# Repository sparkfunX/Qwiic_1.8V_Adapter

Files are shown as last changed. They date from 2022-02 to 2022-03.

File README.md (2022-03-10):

SparkFun Qwiic 1.8V Adapter
========================================

Qwiic 1.8V Adapter

[*Qwiic 1.8V Adapter (SPX-19017)*](https://www.sparkfun.com/products/19017)

Our [Qwiic Connect System](https://www.sparkfun.com/qwiic) is designed to help you quickly interface development boards and breakouts in your project or prototype. One way the Qwiic system achieves this is by standardizing on a single bus voltage of 3.3 Volts. This means that any Qwiic-compatible board that's based on a 1.8V part has an on-board voltage regulator and logic level translator, but what if you have a 1.8V part with no breakout board and you need to get integrated into your Qwiic project? No worries! This Qwiic 1.8V Adapter supplies 1.8V at up to 300mA as well as bi-directional logic level translation so that you can connect your Qwiic system to any 1.8V I²C part you can find! Simply connect the adapter to your bus using a Qwiic cable, connect your 1.8V part to the header pins marked "1.8V," and now your part is on the 3.3V Qwiic bus! As on other Qwiic boards, we've also broken out the 3.3V pins to a 0.1" header and added two Qwiic connectors, making it easy to connect in line with all of your other Qwiic boards.

Repository Contents
-------------------

* **/Documentation** - Data sheets, additional product information
* **/Hardware** - Eagle design files (.brd, .sch)
* **/Production** - Production panel files (.brd)

License Information
-------------------

This product is _**open source**_! 

Please review the LICENSE.md file for license information. 

If you have any questions or concerns on licensing, please contact technical support on our [SparkFun forums](https://forum.sparkfun.com/viewforum.php?f=152).

Distributed as-is; no warranty is given.

- Your friends at SparkFun.

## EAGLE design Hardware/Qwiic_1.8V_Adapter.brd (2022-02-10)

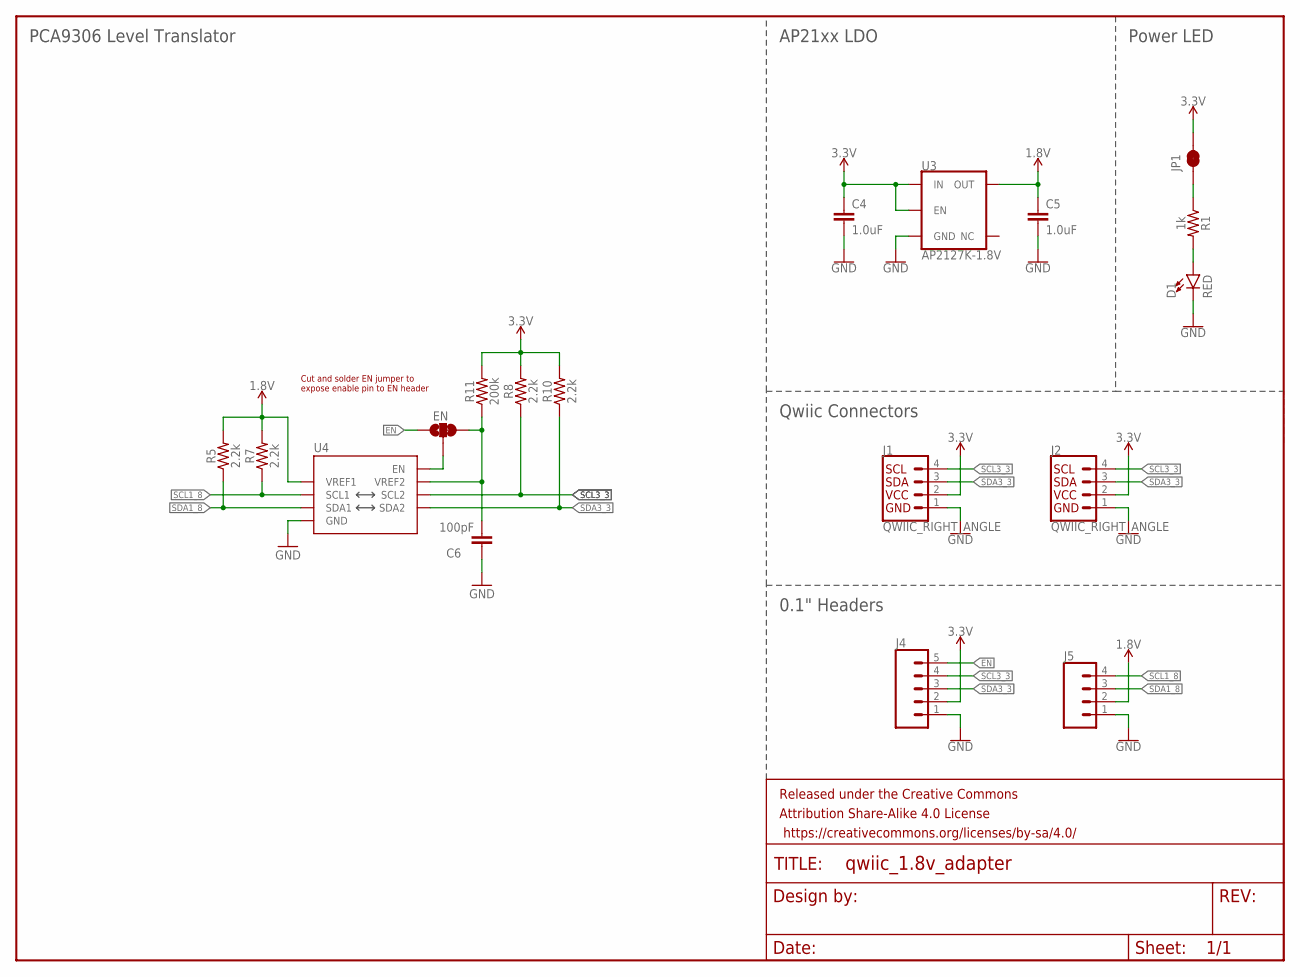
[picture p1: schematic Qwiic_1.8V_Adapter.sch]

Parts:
C4, C5: 1.0uF; 0603
C6: 100pF; 0603
D1: RED; LED-0603
EN: JUMPER-SMT_3_1-NC_TRACE_SILK; SMT-JUMPER_3_1-NC_TRACE_SILK
FRAME1: FRAME-LETTER; CREATIVE_COMMONS
J1, J2: QWIIC_RIGHT_ANGLE; JST04_1MM_RA
J4: CONN_05NO_SILK; 1X05_NO_SILK
J5: CONN_041X04_NO_SILK; 1X04_NO_SILK
JP1: JUMPER-SMT_2_NC_TRACE_SILK; SMT-JUMPER_2_NC_TRACE_SILK
R1: 1k; 0603
R5, R7, R8, R10: 2.2k; 0603
R11: 200k; 0603
U3: AP2127K-1.8V; SOT23-5
U4: PCA9306VSSOP_8PIN; VSSOP_8PIN

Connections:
1.8V: C5.1, J5.2, R5.2, R7.2, U3.5 (OUT), U4.P2 (VREF1)
3.3V: C4.1, J1.2, J2.2, J4.2, JP1.2, R8.2, R10.2, R11.2, U3.1 (IN), U3.3 (EN)
EN: EN.1, J4.5
GND: C4.2, C5.2, C6.1, D1.C, J1.1, J2.1, J4.1, J5.1, U3.2 (GND), U4.P1 (GND)
unnamed: EN.2, U4.P8 (EN)
unnamed: D1.A, R1.2
unnamed: JP1.1, R1.1
unnamed: C6.2, EN.3, R11.1, U4.P7 (VREF2)
SCL1_8: J5.4, R7.1, U4.P3 (SCL1)
SCL3_3: J1.4, J2.4, J4.4, R8.1, U4.P6 (SCL2)
SDA1_8: J5.3, R5.1, U4.P4 (SDA1)
SDA3_3: J1.3, J2.3, J4.3, R10.1, U4.P5 (SDA2)

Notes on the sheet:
PCA9306 Level Translator
AP21xx LDO
Power LED
Qwiic Connectors
0.1" Headers
Cut and solder EN jumper to expose enable pin to EN header

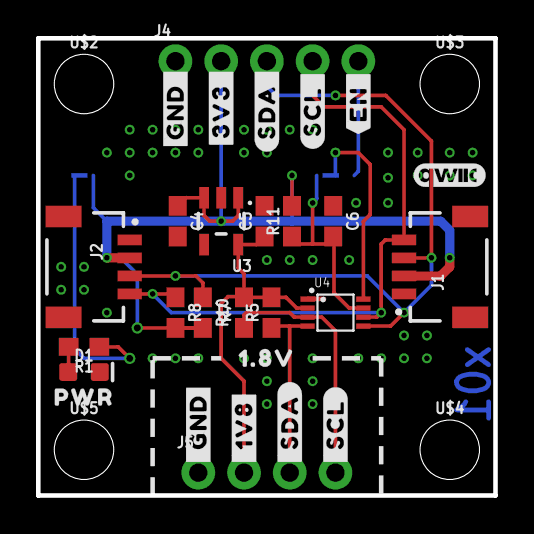
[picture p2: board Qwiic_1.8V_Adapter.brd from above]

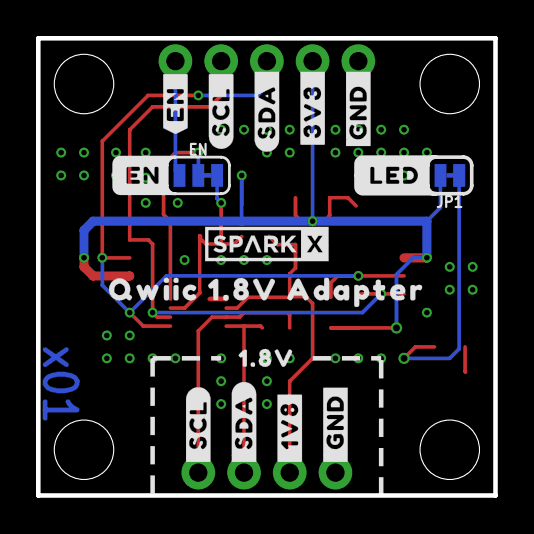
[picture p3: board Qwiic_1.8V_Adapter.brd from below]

Board: 2 copper layers, 25.4 x 25.4 mm, 49 parts (16 on the bottom side), 12 nets.

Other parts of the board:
U$1, U$17: #_GND#0
U$2, U$3, U$4, U$5: STAND-OFF
U$6, U$18: #_1V8#0
U$7, U$19: #_SDA#0
U$8, U$20: #_SCL#0
U$9: PWR0
U$10, U$21: #GND_#0
U$11, U$22: #3V3_#0
U$12, U$23: #SDA_#0
U$13, U$24: #SCL_#0
U$14, U$25: #EN_#0
U$15, U$26: 1#8V0
U$16: QWIIC_4MM
U$27: #EN#0
U$28: QWIIC_1#8V_ADAPTER0
U$29: SPARKX-SMALL
U$30: #LED#0

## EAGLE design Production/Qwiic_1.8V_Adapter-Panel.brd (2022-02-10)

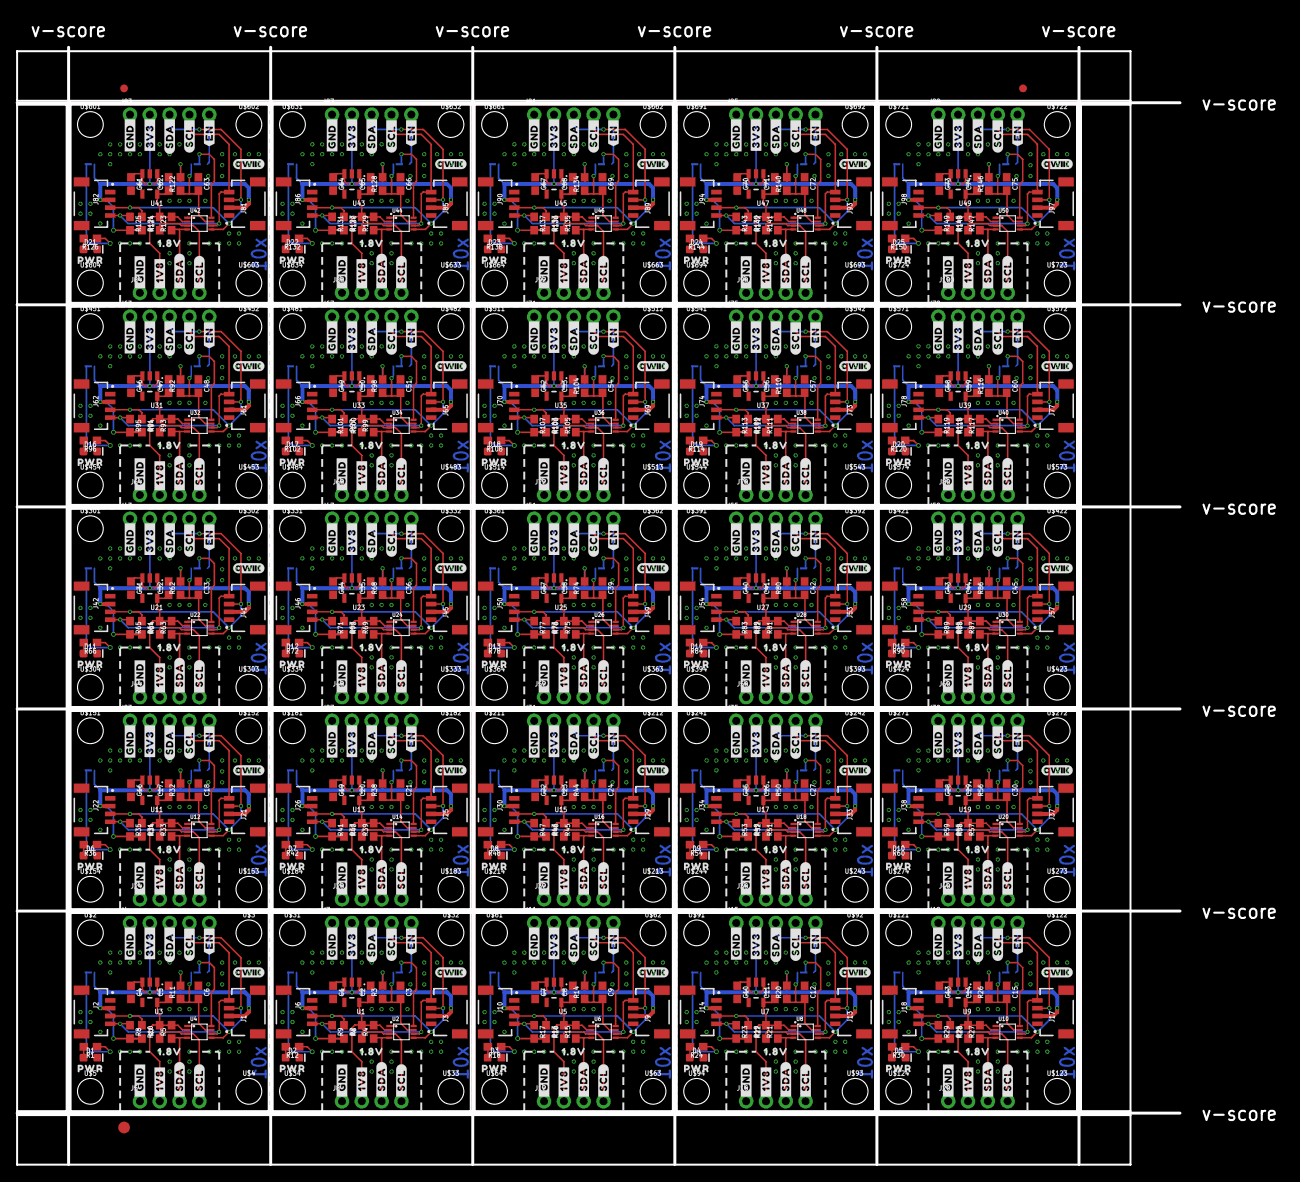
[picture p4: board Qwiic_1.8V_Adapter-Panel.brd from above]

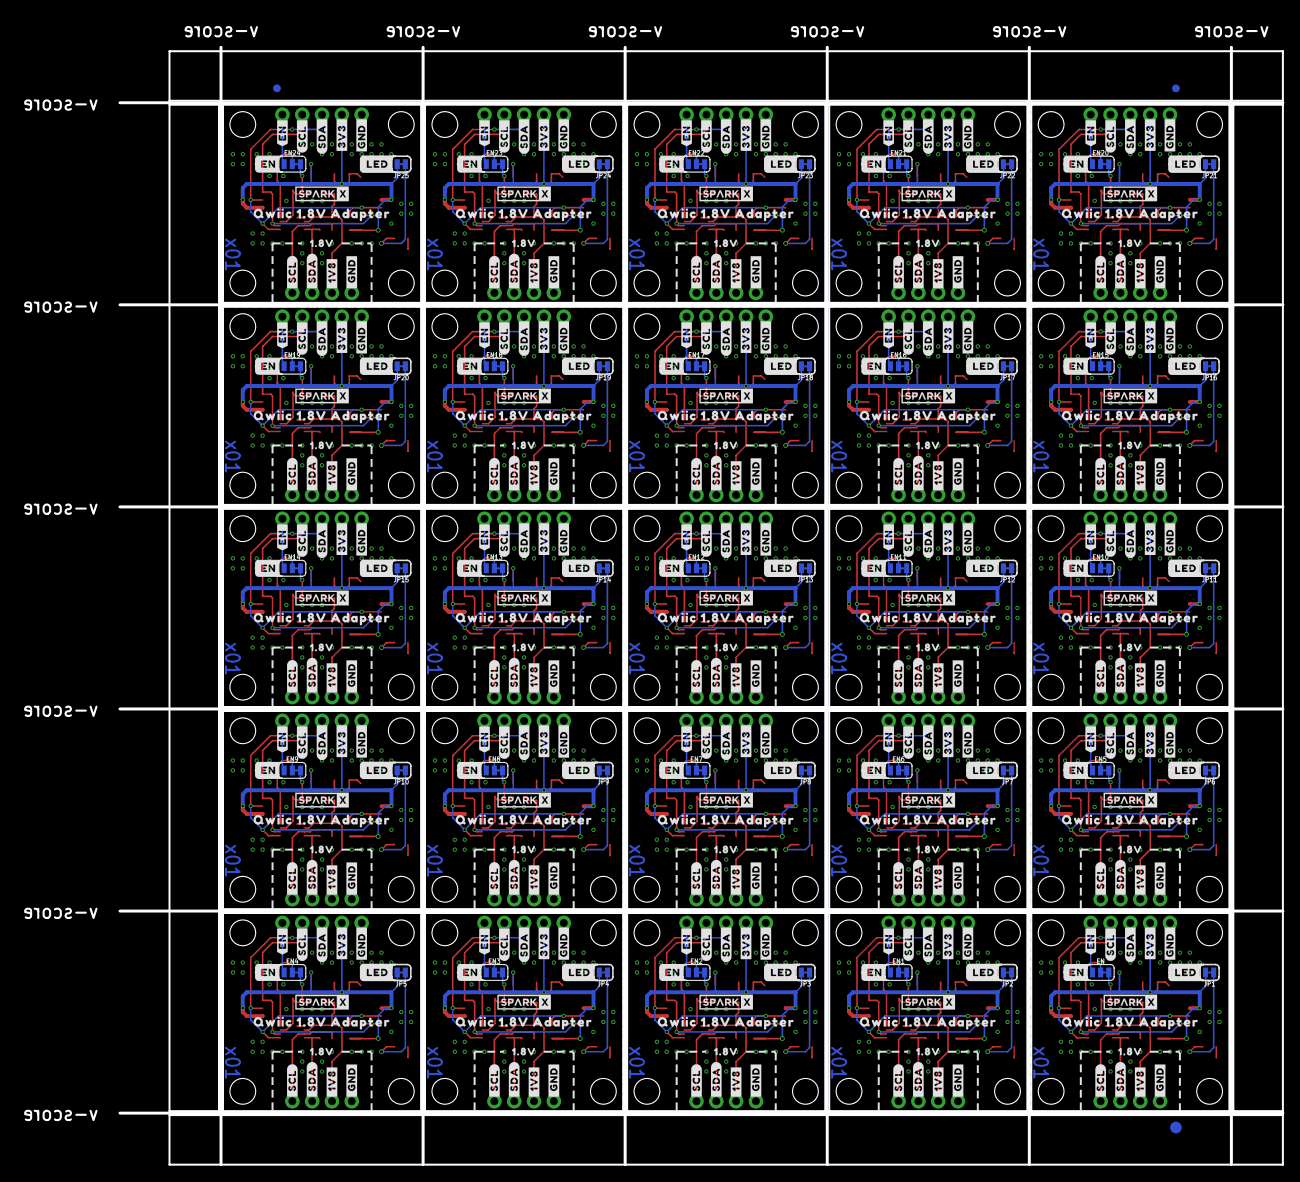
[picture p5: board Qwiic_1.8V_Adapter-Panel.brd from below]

Board: 2 copper layers, 149.1 x 143.3 mm, 1206 parts (403 on the bottom side), 300 nets.

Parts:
C1, C2, C4, C5, C7, C8, C10, C11, C13, C14, C16, C17, C19, C20, C22, C23, C25, C26, C28, C29, C31, C32, C34, C35, C37, C38, C40, C41, C43, C44, C46, C47, C49, C50, C52, C53, C55, C56, C58, C59, C61, C62, C64, C65, C67, C68, C70, C71, C73, C74: 1.0uF; 0603
C3, C6, C9, C12, C15, C18, C21, C24, C27, C30, C33, C36, C39, C42, C45, C48, C51, C54, C57, C60, C63, C66, C69, C72, C75: 100pF; 0603
D1, D2, D3, D4, D5, D6, D7, D8, D9, D10, D11, D12, D13, D14, D15, D16, D17, D18, D19, D20, D21, D22, D23, D24, D25: RED; LED-0603
E$1, E$2, E$3, E$4: FIDUCIAL-1X2
E$5, E$6: FIDUCIAL-1.5X3
EN, EN1, EN2, EN3, EN4, EN5, EN6, EN7, EN8, EN9, EN10, EN11, EN12, EN13, EN14, EN15, EN16, EN17, EN18, EN19, EN20, EN21, EN22, EN23, EN24: JUMPER-SMT_3_1-NC_TRACE_SILK; SMT-JUMPER_3_1-NC_TRACE_SILK
J1, J2, J3, J6, J9, J10, J13, J14, J17, J18, J21, J22, J25, J26, J29, J30, J33, J34, J37, J38, J41, J42, J45, J46, J49, J50, J53, J54, J57, J58, J61, J62, J65, J66, J69, J70, J73, J74, J77, J78, J81, J82, J85, J86, J89, J90, J93, J94, J97, J98: QWIIC_RIGHT_ANGLE; JST04_1MM_RA
J4, J7, J11, J15, J19, J23, J27, J31, J35, J39, J43, J47, J51, J55, J59, J63, J67, J71, J75, J79, J83, J87, J91, J95, J99: 1X05_NO_SILK
J5, J8, J12, J16, J20, J24, J28, J32, J36, J40, J44, J48, J52, J56, J60, J64, J68, J72, J76, J80, J84, J88, J92, J96, J100: 1X04_NO_SILK
JP1, JP2, JP3, JP4, JP5, JP6, JP7, JP8, JP9, JP10, JP11, JP12, JP13, JP14, JP15, JP16, JP17, JP18, JP19, JP20, JP21, JP22, JP23, JP24, JP25: JUMPER-SMT_2_NC_TRACE_SILK; SMT-JUMPER_2_NC_TRACE_SILK
R1, R12, R18, R24, R30, R36, R42, R48, R54, R60, R66, R72, R78, R84, R90, R96, R102, R108, R114, R120, R126, R132, R138, R144, R150: 1k; 0603
R2, R4, R5, R6, R7, R8, R9, R10, R13, R15, R16, R17, R19, R21, R22, R23, R25, R27, R28, R29, R31, R33, R34, R35, R37, R39, R40, R41, R43, R45, R46, R47, R49, R51, R52, R53, R55, R57, R58, R59, R61, R63, R64, R65, R67, R69, R70, R71, R73, R75, R76, R77, R79, R81, R82, R83, R85, R87, R88, R89, R91, R93, R94, R95, R97, R99, R100, R101, R103, R105, R106, R107, R109, R111, R112, R113, R115, R117, R118, R119, R121, R123, R124, R125, R127, R129, R130, R131, R133, R135, R136, R137, R139, R141, R142, R143, R145, R147, R148, R149: 2.2k; 0603
R3, R11, R14, R20, R26, R32, R38, R44, R50, R56, R62, R68, R74, R80, R86, R92, R98, R104, R110, R116, R122, R128, R134, R140, R146: 200k; 0603
U1, U3, U5, U7, U9, U11, U13, U15, U17, U19, U21, U23, U25, U27, U29, U31, U33, U35, U37, U39, U41, U43, U45, U47, U49: AP2127K-1.8V; SOT23-5
U2, U4, U6, U8, U10, U12, U14, U16, U18, U20, U22, U24, U26, U28, U30, U32, U34, U36, U38, U40, U42, U44, U46, U48, U50: VSSOP_8PIN
U$1, U$17, U$35, U$47, U$65, U$77, U$95, U$107, U$125, U$137, U$155, U$167, U$185, U$197, U$215, U$227, U$245, U$257, U$275, U$287, U$305, U$317, U$335, U$347, U$365, U$377, U$395, U$407, U$425, U$437, U$455, U$467, U$485, U$497, U$515, U$527, U$545, U$557, U$575, U$587, U$605, U$617, U$635, U$647, U$665, U$677, U$695, U$707, U$725, U$737: #_GND#0
U$2, U$3, U$4, U$5, U$31, U$32, U$33, U$34, U$61, U$62, U$63, U$64, U$91, U$92, U$93, U$94, U$121, U$122, U$123, U$124, U$151, U$152, U$153, U$154, U$181, U$182, U$183, U$184, U$211, U$212, U$213, U$214, U$241, U$242, U$243, U$244, U$271, U$272, U$273, U$274, U$301, U$302, U$303, U$304, U$331, U$332, U$333, U$334, U$361, U$362, U$363, U$364, U$391, U$392, U$393, U$394, U$421, U$422, U$423, U$424, U$451, U$452, U$453, U$454, U$481, U$482, U$483, U$484, U$511, U$512, U$513, U$514, U$541, U$542, U$543, U$544, U$571, U$572, U$573, U$574, U$601, U$602, U$603, U$604, U$631, U$632, U$633, U$634, U$661, U$662, U$663, U$664, U$691, U$692, U$693, U$694, U$721, U$722, U$723, U$724: STAND-OFF
U$6, U$18, U$36, U$48, U$66, U$78, U$96, U$108, U$126, U$138, U$156, U$168, U$186, U$198, U$216, U$228, U$246, U$258, U$276, U$288, U$306, U$318, U$336, U$348, U$366, U$378, U$396, U$408, U$426, U$438, U$456, U$468, U$486, U$498, U$516, U$528, U$546, U$558, U$576, U$588, U$606, U$618, U$636, U$648, U$666, U$678, U$696, U$708, U$726, U$738: #_1V8#0
U$7, U$19, U$37, U$49, U$67, U$79, U$97, U$109, U$127, U$139, U$157, U$169, U$187, U$199, U$217, U$229, U$247, U$259, U$277, U$289, U$307, U$319, U$337, U$349, U$367, U$379, U$397, U$409, U$427, U$439, U$457, U$469, U$487, U$499, U$517, U$529, U$547, U$559, U$577, U$589, U$607, U$619, U$637, U$649, U$667, U$679, U$697, U$709, U$727, U$739: #_SDA#0
U$8, U$20, U$38, U$50, U$68, U$80, U$98, U$110, U$128, U$140, U$158, U$170, U$188, U$200, U$218, U$230, U$248, U$260, U$278, U$290, U$308, U$320, U$338, U$350, U$368, U$380, U$398, U$410, U$428, U$440, U$458, U$470, U$488, U$500, U$518, U$530, U$548, U$560, U$578, U$590, U$608, U$620, U$638, U$650, U$668, U$680, U$698, U$710, U$728, U$740: #_SCL#0
U$9, U$39, U$69, U$99, U$129, U$159, U$189, U$219, U$249, U$279, U$309, U$339, U$369, U$399, U$429, U$459, U$489, U$519, U$549, U$579, U$609, U$639, U$669, U$699, U$729: PWR0
U$10, U$21, U$40, U$51, U$70, U$81, U$100, U$111, U$130, U$141, U$160, U$171, U$190, U$201, U$220, U$231, U$250, U$261, U$280, U$291, U$310, U$321, U$340, U$351, U$370, U$381, U$400, U$411, U$430, U$441, U$460, U$471, U$490, U$501, U$520, U$531, U$550, U$561, U$580, U$591, U$610, U$621, U$640, U$651, U$670, U$681, U$700, U$711, U$730, U$741: #GND_#0
U$11, U$22, U$41, U$52, U$71, U$82, U$101, U$112, U$131, U$142, U$161, U$172, U$191, U$202, U$221, U$232, U$251, U$262, U$281, U$292, U$311, U$322, U$341, U$352, U$371, U$382, U$401, U$412, U$431, U$442, U$461, U$472, U$491, U$502, U$521, U$532, U$551, U$562, U$581, U$592, U$611, U$622, U$641, U$652, U$671, U$682, U$701, U$712, U$731, U$742: #3V3_#0
U$12, U$23, U$42, U$53, U$72, U$83, U$102, U$113, U$132, U$143, U$162, U$173, U$192, U$203, U$222, U$233, U$252, U$263, U$282, U$293, U$312, U$323, U$342, U$353, U$372, U$383, U$402, U$413, U$432, U$443, U$462, U$473, U$492, U$503, U$522, U$533, U$552, U$563, U$582, U$593, U$612, U$623, U$642, U$653, U$672, U$683, U$702, U$713, U$732, U$743: #SDA_#0
U$13, U$24, U$43, U$54, U$73, U$84, U$103, U$114, U$133, U$144, U$163, U$174, U$193, U$204, U$223, U$234, U$253, U$264, U$283, U$294, U$313, U$324, U$343, U$354, U$373, U$384, U$403, U$414, U$433, U$444, U$463, U$474, U$493, U$504, U$523, U$534, U$553, U$564, U$583, U$594, U$613, U$624, U$643, U$654, U$673, U$684, U$703, U$714, U$733, U$744: #SCL_#0
U$14, U$25, U$44, U$55, U$74, U$85, U$104, U$115, U$134, U$145, U$164, U$175, U$194, U$205, U$224, U$235, U$254, U$265, U$284, U$295, U$314, U$325, U$344, U$355, U$374, U$385, U$404, U$415, U$434, U$445, U$464, U$475, U$494, U$505, U$524, U$535, U$554, U$565, U$584, U$595, U$614, U$625, U$644, U$655, U$674, U$685, U$704, U$715, U$734, U$745: #EN_#0
U$15, U$26, U$45, U$56, U$75, U$86, U$105, U$116, U$135, U$146, U$165, U$176, U$195, U$206, U$225, U$236, U$255, U$266, U$285, U$296, U$315, U$326, U$345, U$356, U$375, U$386, U$405, U$416, U$435, U$446, U$465, U$476, U$495, U$506, U$525, U$536, U$555, U$566, U$585, U$596, U$615, U$626, U$645, U$656, U$675, U$686, U$705, U$716, U$735, U$746: 1#8V0
U$16, U$46, U$76, U$106, U$136, U$166, U$196, U$226, U$256, U$286, U$316, U$346, U$376, U$406, U$436, U$466, U$496, U$526, U$556, U$586, U$616, U$646, U$676, U$706, U$736: QWIIC_4MM
U$27, U$57, U$87, U$117, U$147, U$177, U$207, U$237, U$267, U$297, U$327, U$357, U$387, U$417, U$447, U$477, U$507, U$537, U$567, U$597, U$627, U$657, U$687, U$717, U$747: #EN#0
U$28, U$58, U$88, U$118, U$148, U$178, U$208, U$238, U$268, U$298, U$328, U$358, U$388, U$418, U$448, U$478, U$508, U$538, U$568, U$598, U$628, U$658, U$688, U$718, U$748: QWIIC_1#8V_ADAPTER0
U$29, U$59, U$89, U$119, U$149, U$179, U$209, U$239, U$269, U$299, U$329, U$359, U$389, U$419, U$449, U$479, U$509, U$539, U$569, U$599, U$629, U$659, U$689, U$719, U$749: SPARKX-SMALL
U$30, U$60, U$90, U$120, U$150, U$180, U$210, U$240, U$270, U$300, U$330, U$360, U$390, U$420, U$450, U$480, U$510, U$540, U$570, U$600, U$630, U$660, U$690, U$720, U$750: #LED#0

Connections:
1.8V: C5.1, J5.2, R5.2, R7.2, U3.5, U4.P2
1.8V1: C2.1, J8.2, R4.2, R6.2, U1.5, U2.P2
1.8V2: C8.1, J12.2, R15.2, R16.2, U5.5, U6.P2
1.8V3: C11.1, J16.2, R21.2, R22.2, U7.5, U8.P2
1.8V4: C14.1, J20.2, R27.2, R28.2, U9.5, U10.P2
1.8V5: C17.1, J24.2, R33.2, R34.2, U11.5, U12.P2
1.8V6: C20.1, J28.2, R39.2, R40.2, U13.5, U14.P2
1.8V7: C23.1, J32.2, R45.2, R46.2, U15.5, U16.P2
1.8V8: C26.1, J36.2, R51.2, R52.2, U17.5, U18.P2
1.8V9: C29.1, J40.2, R57.2, R58.2, U19.5, U20.P2
1.8V10: C32.1, J44.2, R63.2, R64.2, U21.5, U22.P2
1.8V11: C35.1, J48.2, R69.2, R70.2, U23.5, U24.P2
1.8V12: C38.1, J52.2, R75.2, R76.2, U25.5, U26.P2
1.8V13: C41.1, J56.2, R81.2, R82.2, U27.5, U28.P2
1.8V14: C44.1, J60.2, R87.2, R88.2, U29.5, U30.P2
1.8V15: C47.1, J64.2, R93.2, R94.2, U31.5, U32.P2
1.8V16: C50.1, J68.2, R99.2, R100.2, U33.5, U34.P2
1.8V17: C53.1, J72.2, R105.2, R106.2, U35.5, U36.P2
1.8V18: C56.1, J76.2, R111.2, R112.2, U37.5, U38.P2
1.8V19: C59.1, J80.2, R117.2, R118.2, U39.5, U40.P2
1.8V20: C62.1, J84.2, R123.2, R124.2, U41.5, U42.P2
1.8V21: C65.1, J88.2, R129.2, R130.2, U43.5, U44.P2
1.8V22: C68.1, J92.2, R135.2, R136.2, U45.5, U46.P2
1.8V23: C71.1, J96.2, R141.2, R142.2, U47.5, U48.P2
1.8V24: C74.1, J100.2, R147.2, R148.2, U49.5, U50.P2
3.3V: C4.1, J1.2, J2.2, J4.2, JP1.2, R8.2, R10.2, R11.2, U3.1, U3.3
3.3V1: C1.1, J3.2, J6.2, J7.2, JP2.2, R2.2, R3.2, R9.2, U1.1, U1.3
3.3V2: C7.1, J9.2, J10.2, J11.2, JP3.2, R13.2, R14.2, R17.2, U5.1, U5.3
3.3V3: C10.1, J13.2, J14.2, J15.2, JP4.2, R19.2, R20.2, R23.2, U7.1, U7.3
3.3V4: C13.1, J17.2, J18.2, J19.2, JP5.2, R25.2, R26.2, R29.2, U9.1, U9.3
3.3V5: C16.1, J21.2, J22.2, J23.2, JP6.2, R31.2, R32.2, R35.2, U11.1, U11.3
3.3V6: C19.1, J25.2, J26.2, J27.2, JP7.2, R37.2, R38.2, R41.2, U13.1, U13.3
3.3V7: C22.1, J29.2, J30.2, J31.2, JP8.2, R43.2, R44.2, R47.2, U15.1, U15.3
3.3V8: C25.1, J33.2, J34.2, J35.2, JP9.2, R49.2, R50.2, R53.2, U17.1, U17.3
3.3V9: C28.1, J37.2, J38.2, J39.2, JP10.2, R55.2, R56.2, R59.2, U19.1, U19.3
3.3V10: C31.1, J41.2, J42.2, J43.2, JP11.2, R61.2, R62.2, R65.2, U21.1, U21.3
3.3V11: C34.1, J45.2, J46.2, J47.2, JP12.2, R67.2, R68.2, R71.2, U23.1, U23.3
3.3V12: C37.1, J49.2, J50.2, J51.2, JP13.2, R73.2, R74.2, R77.2, U25.1, U25.3
3.3V13: C40.1, J53.2, J54.2, J55.2, JP14.2, R79.2, R80.2, R83.2, U27.1, U27.3
3.3V14: C43.1, J57.2, J58.2, J59.2, JP15.2, R85.2, R86.2, R89.2, U29.1, U29.3
3.3V15: C46.1, J61.2, J62.2, J63.2, JP16.2, R91.2, R92.2, R95.2, U31.1, U31.3
3.3V16: C49.1, J65.2, J66.2, J67.2, JP17.2, R97.2, R98.2, R101.2, U33.1, U33.3
3.3V17: C52.1, J69.2, J70.2, J71.2, JP18.2, R103.2, R104.2, R107.2, U35.1, U35.3
3.3V18: C55.1, J73.2, J74.2, J75.2, JP19.2, R109.2, R110.2, R113.2, U37.1, U37.3
3.3V19: C58.1, J77.2, J78.2, J79.2, JP20.2, R115.2, R116.2, R119.2, U39.1, U39.3
3.3V20: C61.1, J81.2, J82.2, J83.2, JP21.2, R121.2, R122.2, R125.2, U41.1, U41.3
3.3V21: C64.1, J85.2, J86.2, J87.2, JP22.2, R127.2, R128.2, R131.2, U43.1, U43.3
3.3V22: C67.1, J89.2, J90.2, J91.2, JP23.2, R133.2, R134.2, R137.2, U45.1, U45.3
3.3V23: C70.1, J93.2, J94.2, J95.2, JP24.2, R139.2, R140.2, R143.2, U47.1, U47.3
3.3V24: C73.1, J97.2, J98.2, J99.2, JP25.2, R145.2, R146.2, R149.2, U49.1, U49.3
EN: EN.1, J4.5
EN1: EN1.1, J7.5
EN2: EN2.1, J11.5
EN3: EN3.1, J15.5
EN4: EN4.1, J19.5
EN5: EN5.1, J23.5
EN6: EN6.1, J27.5
EN7: EN7.1, J31.5
EN8: EN8.1, J35.5
EN9: EN9.1, J39.5
EN10: EN10.1, J43.5
EN11: EN11.1, J47.5
EN12: EN12.1, J51.5
EN13: EN13.1, J55.5
EN14: EN14.1, J59.5
EN15: EN15.1, J63.5
EN16: EN16.1, J67.5
EN17: EN17.1, J71.5
EN18: EN18.1, J75.5
EN19: EN19.1, J79.5
EN20: EN20.1, J83.5
EN21: EN21.1, J87.5
EN22: EN22.1, J91.5
EN23: EN23.1, J95.5
EN24: EN24.1, J99.5
GND: C4.2, C5.2, C6.1, D1.C, J1.1, J2.1, J4.1, J5.1, U3.2, U4.P1
GND1: C1.2, C2.2, C3.1, D2.C, J3.1, J6.1, J7.1, J8.1, U1.2, U2.P1
GND2: C7.2, C8.2, C9.1, D3.C, J9.1, J10.1, J11.1, J12.1, U5.2, U6.P1
GND3: C10.2, C11.2, C12.1, D4.C, J13.1, J14.1, J15.1, J16.1, U7.2, U8.P1
GND4: C13.2, C14.2, C15.1, D5.C, J17.1, J18.1, J19.1, J20.1, U9.2, U10.P1
GND5: C16.2, C17.2, C18.1, D6.C, J21.1, J22.1, J23.1, J24.1, U11.2, U12.P1
GND6: C19.2, C20.2, C21.1, D7.C, J25.1, J26.1, J27.1, J28.1, U13.2, U14.P1
GND7: C22.2, C23.2, C24.1, D8.C, J29.1, J30.1, J31.1, J32.1, U15.2, U16.P1
GND8: C25.2, C26.2, C27.1, D9.C, J33.1, J34.1, J35.1, J36.1, U17.2, U18.P1
GND9: C28.2, C29.2, C30.1, D10.C, J37.1, J38.1, J39.1, J40.1, U19.2, U20.P1
GND10: C31.2, C32.2, C33.1, D11.C, J41.1, J42.1, J43.1, J44.1, U21.2, U22.P1
GND11: C34.2, C35.2, C36.1, D12.C, J45.1, J46.1, J47.1, J48.1, U23.2, U24.P1
GND12: C37.2, C38.2, C39.1, D13.C, J49.1, J50.1, J51.1, J52.1, U25.2, U26.P1
GND13: C40.2, C41.2, C42.1, D14.C, J53.1, J54.1, J55.1, J56.1, U27.2, U28.P1
GND14: C43.2, C44.2, C45.1, D15.C, J57.1, J58.1, J59.1, J60.1, U29.2, U30.P1
GND15: C46.2, C47.2, C48.1, D16.C, J61.1, J62.1, J63.1, J64.1, U31.2, U32.P1
GND16: C49.2, C50.2, C51.1, D17.C, J65.1, J66.1, J67.1, J68.1, U33.2, U34.P1
GND17: C52.2, C53.2, C54.1, D18.C, J69.1, J70.1, J71.1, J72.1, U35.2, U36.P1
GND18: C55.2, C56.2, C57.1, D19.C, J73.1, J74.1, J75.1, J76.1, U37.2, U38.P1
GND19: C58.2, C59.2, C60.1, D20.C, J77.1, J78.1, J79.1, J80.1, U39.2, U40.P1
GND20: C61.2, C62.2, C63.1, D21.C, J81.1, J82.1, J83.1, J84.1, U41.2, U42.P1
GND21: C64.2, C65.2, C66.1, D22.C, J85.1, J86.1, J87.1, J88.1, U43.2, U44.P1
GND22: C67.2, C68.2, C69.1, D23.C, J89.1, J90.1, J91.1, J92.1, U45.2, U46.P1
GND23: C70.2, C71.2, C72.1, D24.C, J93.1, J94.1, J95.1, J96.1, U47.2, U48.P1
GND24: C73.2, C74.2, C75.1, D25.C, J97.1, J98.1, J99.1, J100.1, U49.2, U50.P1
unnamed: EN.2, U4.P8
unnamed: D1.A, R1.2
unnamed: JP1.1, R1.1
unnamed: C3.2, EN1.3, R3.1, U2.P7
unnamed: EN1.2, U2.P8
unnamed: D2.A, R12.2
unnamed: JP2.1, R12.1
unnamed: C9.2, EN2.3, R14.1, U6.P7
unnamed: EN2.2, U6.P8
unnamed: D3.A, R18.2
unnamed: JP3.1, R18.1
unnamed: C12.2, EN3.3, R20.1, U8.P7
unnamed: EN3.2, U8.P8
unnamed: D4.A, R24.2
unnamed: JP4.1, R24.1
unnamed: C15.2, EN4.3, R26.1, U10.P7
unnamed: EN4.2, U10.P8
unnamed: D5.A, R30.2
unnamed: JP5.1, R30.1
unnamed: C18.2, EN5.3, R32.1, U12.P7
unnamed: EN5.2, U12.P8
unnamed: D6.A, R36.2
unnamed: JP6.1, R36.1
unnamed: C21.2, EN6.3, R38.1, U14.P7
unnamed: EN6.2, U14.P8
unnamed: D7.A, R42.2
unnamed: JP7.1, R42.1
unnamed: C24.2, EN7.3, R44.1, U16.P7
unnamed: EN7.2, U16.P8
unnamed: D8.A, R48.2
unnamed: JP8.1, R48.1
unnamed: C27.2, EN8.3, R50.1, U18.P7
unnamed: EN8.2, U18.P8
unnamed: D9.A, R54.2
unnamed: JP9.1, R54.1
unnamed: C30.2, EN9.3, R56.1, U20.P7
unnamed: EN9.2, U20.P8
unnamed: D10.A, R60.2
unnamed: JP10.1, R60.1
unnamed: C6.2, EN.3, R11.1, U4.P7
unnamed: C33.2, EN10.3, R62.1, U22.P7
unnamed: EN10.2, U22.P8
unnamed: D11.A, R66.2
unnamed: JP11.1, R66.1
unnamed: C36.2, EN11.3, R68.1, U24.P7
unnamed: EN11.2, U24.P8
unnamed: D12.A, R72.2
unnamed: JP12.1, R72.1
unnamed: C39.2, EN12.3, R74.1, U26.P7
unnamed: EN12.2, U26.P8
unnamed: D13.A, R78.2
unnamed: JP13.1, R78.1
unnamed: C42.2, EN13.3, R80.1, U28.P7
unnamed: EN13.2, U28.P8
unnamed: D14.A, R84.2
unnamed: JP14.1, R84.1
unnamed: C45.2, EN14.3, R86.1, U30.P7
unnamed: EN14.2, U30.P8
unnamed: D15.A, R90.2
unnamed: JP15.1, R90.1
unnamed: C48.2, EN15.3, R92.1, U32.P7
unnamed: EN15.2, U32.P8
unnamed: D16.A, R96.2
unnamed: JP16.1, R96.1
unnamed: C51.2, EN16.3, R98.1, U34.P7
unnamed: EN16.2, U34.P8
unnamed: D17.A, R102.2
unnamed: JP17.1, R102.1
unnamed: C54.2, EN17.3, R104.1, U36.P7
unnamed: EN17.2, U36.P8
unnamed: D18.A, R108.2
unnamed: JP18.1, R108.1
unnamed: C57.2, EN18.3, R110.1, U38.P7
unnamed: EN18.2, U38.P8
unnamed: D19.A, R114.2
unnamed: JP19.1, R114.1
unnamed: C60.2, EN19.3, R116.1, U40.P7
unnamed: EN19.2, U40.P8
unnamed: D20.A, R120.2
unnamed: JP20.1, R120.1
unnamed: C63.2, EN20.3, R122.1, U42.P7
unnamed: EN20.2, U42.P8
unnamed: D21.A, R126.2
unnamed: JP21.1, R126.1
unnamed: C66.2, EN21.3, R128.1, U44.P7
unnamed: EN21.2, U44.P8
unnamed: D22.A, R132.2
unnamed: JP22.1, R132.1
unnamed: C69.2, EN22.3, R134.1, U46.P7
unnamed: EN22.2, U46.P8
unnamed: D23.A, R138.2
unnamed: JP23.1, R138.1
unnamed: C72.2, EN23.3, R140.1, U48.P7
unnamed: EN23.2, U48.P8
unnamed: D24.A, R144.2
unnamed: JP24.1, R144.1
unnamed: C75.2, EN24.3, R146.1, U50.P7
unnamed: EN24.2, U50.P8
unnamed: D25.A, R150.2
unnamed: JP25.1, R150.1
SCL1_1: J8.4, R6.1, U2.P3
SCL1_2: J12.4, R16.1, U6.P3
SCL1_3: J16.4, R22.1, U8.P3
SCL1_4: J20.4, R28.1, U10.P3
SCL1_5: J24.4, R34.1, U12.P3
SCL1_6: J28.4, R40.1, U14.P3
SCL1_7: J32.4, R46.1, U16.P3
SCL1_8: J5.4, R7.1, U4.P3
SCL1_9: J36.4, R52.1, U18.P3
SCL1_10: J40.4, R58.1, U20.P3
SCL1_11: J44.4, R64.1, U22.P3
SCL1_12: J48.4, R70.1, U24.P3
SCL1_13: J52.4, R76.1, U26.P3
SCL1_14: J56.4, R82.1, U28.P3
SCL1_15: J60.4, R88.1, U30.P3
SCL1_16: J64.4, R94.1, U32.P3
SCL1_17: J68.4, R100.1, U34.P3
SCL1_18: J72.4, R106.1, U36.P3
SCL1_19: J76.4, R112.1, U38.P3
SCL1_20: J80.4, R118.1, U40.P3
SCL1_21: J84.4, R124.1, U42.P3
SCL1_22: J88.4, R130.1, U44.P3
SCL1_23: J92.4, R136.1, U46.P3
SCL1_24: J96.4, R142.1, U48.P3
SCL1_25: J100.4, R148.1, U50.P3
SCL3_1: J3.4, J6.4, J7.4, R9.1, U2.P6
SCL3_2: J9.4, J10.4, J11.4, R17.1, U6.P6
SCL3_3: J1.4, J2.4, J4.4, R8.1, U4.P6
SCL3_4: J13.4, J14.4, J15.4, R23.1, U8.P6
SCL3_5: J17.4, J18.4, J19.4, R29.1, U10.P6
SCL3_6: J21.4, J22.4, J23.4, R35.1, U12.P6
SCL3_7: J25.4, J26.4, J27.4, R41.1, U14.P6
SCL3_8: J29.4, J30.4, J31.4, R47.1, U16.P6
SCL3_9: J33.4, J34.4, J35.4, R53.1, U18.P6
SCL3_10: J37.4, J38.4, J39.4, R59.1, U20.P6
SCL3_11: J41.4, J42.4, J43.4, R65.1, U22.P6
SCL3_12: J45.4, J46.4, J47.4, R71.1, U24.P6
SCL3_13: J49.4, J50.4, J51.4, R77.1, U26.P6
SCL3_14: J53.4, J54.4, J55.4, R83.1, U28.P6
SCL3_15: J57.4, J58.4, J59.4, R89.1, U30.P6
SCL3_16: J61.4, J62.4, J63.4, R95.1, U32.P6
SCL3_17: J65.4, J66.4, J67.4, R101.1, U34.P6
SCL3_18: J69.4, J70.4, J71.4, R107.1, U36.P6
SCL3_19: J73.4, J74.4, J75.4, R113.1, U38.P6
SCL3_20: J77.4, J78.4, J79.4, R119.1, U40.P6
SCL3_21: J81.4, J82.4, J83.4, R125.1, U42.P6
SCL3_22: J85.4, J86.4, J87.4, R131.1, U44.P6
SCL3_23: J89.4, J90.4, J91.4, R137.1, U46.P6
SCL3_24: J93.4, J94.4, J95.4, R143.1, U48.P6
SCL3_25: J97.4, J98.4, J99.4, R149.1, U50.P6
SDA1_1: J8.3, R4.1, U2.P4
SDA1_2: J12.3, R15.1, U6.P4
SDA1_3: J16.3, R21.1, U8.P4
SDA1_4: J20.3, R27.1, U10.P4
SDA1_5: J24.3, R33.1, U12.P4
SDA1_6: J28.3, R39.1, U14.P4
SDA1_7: J32.3, R45.1, U16.P4
SDA1_8: J5.3, R5.1, U4.P4
SDA1_9: J36.3, R51.1, U18.P4
SDA1_10: J40.3, R57.1, U20.P4
SDA1_11: J44.3, R63.1, U22.P4
SDA1_12: J48.3, R69.1, U24.P4
SDA1_13: J52.3, R75.1, U26.P4
SDA1_14: J56.3, R81.1, U28.P4
SDA1_15: J60.3, R87.1, U30.P4
SDA1_16: J64.3, R93.1, U32.P4
SDA1_17: J68.3, R99.1, U34.P4
SDA1_18: J72.3, R105.1, U36.P4
SDA1_19: J76.3, R111.1, U38.P4
SDA1_20: J80.3, R117.1, U40.P4
SDA1_21: J84.3, R123.1, U42.P4
SDA1_22: J88.3, R129.1, U44.P4
SDA1_23: J92.3, R135.1, U46.P4
SDA1_24: J96.3, R141.1, U48.P4
SDA1_25: J100.3, R147.1, U50.P4
SDA3_1: J3.3, J6.3, J7.3, R2.1, U2.P5
SDA3_2: J9.3, J10.3, J11.3, R13.1, U6.P5
SDA3_3: J1.3, J2.3, J4.3, R10.1, U4.P5
SDA3_4: J13.3, J14.3, J15.3, R19.1, U8.P5
SDA3_5: J17.3, J18.3, J19.3, R25.1, U10.P5
SDA3_6: J21.3, J22.3, J23.3, R31.1, U12.P5
SDA3_7: J25.3, J26.3, J27.3, R37.1, U14.P5
SDA3_8: J29.3, J30.3, J31.3, R43.1, U16.P5
SDA3_9: J33.3, J34.3, J35.3, R49.1, U18.P5
SDA3_10: J37.3, J38.3, J39.3, R55.1, U20.P5
SDA3_11: J41.3, J42.3, J43.3, R61.1, U22.P5
SDA3_12: J45.3, J46.3, J47.3, R67.1, U24.P5
SDA3_13: J49.3, J50.3, J51.3, R73.1, U26.P5
SDA3_14: J53.3, J54.3, J55.3, R79.1, U28.P5
SDA3_15: J57.3, J58.3, J59.3, R85.1, U30.P5
SDA3_16: J61.3, J62.3, J63.3, R91.1, U32.P5
SDA3_17: J65.3, J66.3, J67.3, R97.1, U34.P5
SDA3_18: J69.3, J70.3, J71.3, R103.1, U36.P5
SDA3_19: J73.3, J74.3, J75.3, R109.1, U38.P5
SDA3_20: J77.3, J78.3, J79.3, R115.1, U40.P5
SDA3_21: J81.3, J82.3, J83.3, R121.1, U42.P5
SDA3_22: J85.3, J86.3, J87.3, R127.1, U44.P5
SDA3_23: J89.3, J90.3, J91.3, R133.1, U46.P5
SDA3_24: J93.3, J94.3, J95.3, R139.1, U48.P5
SDA3_25: J97.3, J98.3, J99.3, R145.1, U50.P5

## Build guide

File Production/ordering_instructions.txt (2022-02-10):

panel size, 143x143mm
PCB thickness, 1.6mm
number of layers, 2
soldermask color, Black
silkscreen color, White
oz copper, 1oz
finish, HASL lead free
stencils, none
pcs per panel, 25
min trace width, 0.2032mm / 0.0080in
min drill size, 0.3048mm / 0.0120in

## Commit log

2021-11-10 x01 pre review
    [Qwiic_1.8V_Adapter.brd, Qwiic_1.8V_Adapter.sch]
2021-11-10 Add EN Jumper note
    [Qwiic_1.8V_Adapter.brd, Qwiic_1.8V_Adapter.sch]
2022-02-10 Production Files and README
    [Qwiic_1.8V_Adapter-Panel.brd, Qwiic_1.8V_Adapter.brd, Qwiic_1.8V_Adapter.sch]

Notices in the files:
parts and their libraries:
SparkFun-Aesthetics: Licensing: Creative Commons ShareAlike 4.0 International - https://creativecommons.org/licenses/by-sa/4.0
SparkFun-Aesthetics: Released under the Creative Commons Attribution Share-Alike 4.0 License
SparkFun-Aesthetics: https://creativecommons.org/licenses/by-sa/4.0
